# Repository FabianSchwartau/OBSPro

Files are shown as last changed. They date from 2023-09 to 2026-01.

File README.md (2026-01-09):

# OBSPro
This is a different version of the OpenBikeSensor main PCB (checkout https://github.com/openbikesensor/OpenBikeSensor_PCB_Board) with a few design goals:
* Optimized for pick-and-place manufacturing. This means no modules for each functionality, everything is on a single board and SMD parts are used.
* Parts only from trustworthy and reliable sources. This also includes that it should be possible to order these parts with a proper bill.
* Software compatibility as far as possible with the original hardware/software.

# PCBA
At the moment we are aiming to get almost all parts from LCSC/JLCPCB, which is a good mixture of trustworthiness/reliability and price. JLC also offers a PCB assemby service, which is used. If you only want one or two boards, it is probably not woth it, but for larger orders it makes perfect sense.

# GPS
There are multiple options for the GPS module. You can use any MAX-8* or MAX-10* from u-blox, which cost around 20€ for single quantities. The pinout is also compatible with the ATGM336H-5N* modules from Zhongkewei. It only costs around 5€, but the performance still needs to be evaluated.

# BOM
Here is a list of parts and potential sources you will need besides the parts listed in the BOM file of the PCB itself.

- THT PCB parts
    - These are also included in the PCB BOM, but not populated by us in the kit.
    - 1x display jack:
        - JST-  S5B-XH-A(LF)(SN): [LCSC](https://www.lcsc.com/product-detail/C263757.html)
    - 1x power switch jack:
        - JST - S2B-XH-A(LF)(SN): [LCSC](https://www.lcsc.com/product-detail/C157931.html)
    - 1x battery jack:
        - XKB Connection - X2510WR-02-N0SN: [LCSC](https://www.lcsc.com/product-detail/C843326.html)
    - 2x ultrasonic transducer
        - HYDZ: HY40A16T12-1: [LCSC](https://www.lcsc.com/product-detail/C17701106.html)
- GPS antenna
    - BAT WIRELESS - BWGNSCNX25-25B1Y2L120: [LCSC](https://www.lcsc.com/product-detail/C784385.html)
- Battery
    - Probably any 18650 style Lipo battery will do. As you need to solder the connectors to the battery, one with U-shaped strips already attached is recommended.
    - Samsung - INR18650-20R [akkuteile.de](https://www.akkuteile.de/lithium-ionen-akkus/18650/samsung/samsung-inr18650-20r-2000mah-3-7v-10c-20a-powertoolzelle-u-loetfahne_1006511_1668)
    - Multiple: [akkuservice-krueger.de](https://www.akkuservice-krueger.de/epages/64221289.sf/de_DE/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) (you can select with solder strip for each battery)
- Battery cable + connector + crimp contacts
    - 1x complete assembly: XKB Connection - X2510T-02-PSN-A22RB-L300-T5: [LCSC](https://www.lcsc.com/product-detail/C7423671.html) (if you buy this, you do not need the parts below)
    - 1x connector: XKB Connection - X2510H-02-N0: [LCSC](https://www.lcsc.com/product-detail/C843320.html)
    - 2x crimp contacts: XKB Connection - X2510T-PSN: [LCSC](https://www.lcsc.com/product-detail/C883292.html)
    - 2x cable (use any ~0.25mm² cable you can find, same for power switch connector)
- 2x zip ties
    - Maximum width: 4.5 mm, minimum length: 70 mm.
    - [LCSC](https://www.lcsc.com/product-detail/C5264191.html), [LCSC](https://www.lcsc.com/product-detail/C4944856.html), [LCSC](https://www.lcsc.com/product-detail/C5197740.html), your local hardware store, ...
- 1x Power switch
    - YUEN FUNG - MT-0-102-A101-M200-RS: [LCSC](https://www.lcsc.com/product-detail/C1788492.html)
- Power switch cable + connector + crimp contacts
    - 1x complete assembly: SHOU HAN - 2.54-2P DT 200mm 24AWG: [LCSC](https://www.lcsc.com/product-detail/C5363463.html) (if you buy this, you do not need the parts below)
    - 1x connector: JST - XHP-2: [LCSC](https://www.lcsc.com/product-detail/C144401.html)
    - 2x crimp contacts: JST - SXH-001T-P0.6: [LCSC](https://www.lcsc.com/product-detail/C140573.html?s_z=n_C140573) (same for the display connector!)
    - 2x cable (use any ~0.25mm² cable you can find, same for battery connector)
- 1x SD card
    - MK - MKUS128M-IGT1: [LCSC](https://www.lcsc.com/product-detail/C22374947.html)
    - SDTRUVAL - SDSDQAB-128M-SDWHA: [LCSC](https://www.lcsc.com/product-detail/C51885978.html)
- 8x Threaded insert nuts M3, ~5mm length, ~4.2mm outer diameter
    - Multiple: [Aliexpress](https://de.aliexpress.com/item/1005003453080262.html), [ruthex](https://www.ruthex.de/products/ruthex-gewindeeinsatz-m3-100-stuck-rx-m3x5-7-messing-gewindebuchsen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), [Amazon](https://www.amazon.de/Einpressmuttern-Einschmelzgewinde-Gewindeeins%C3%A4tze-Inschmelzmuttern-Kunststoffteile/dp/B0D3DZXT4R/), [Amazon](https://www.amazon.de/Gewindeeinsatz-Einschmelzgewinde-Einpressmuttern-Gewindebuchse-Kunststoffschale/dp/B0D17FGQWW/)
- 14x M3x8 screws (DIN912)
    - Used for: 4x main housing, 4x PCB, 3x display housing, 2x display cable strain relive, 4x main housing mounting.
    - Multiple: [Gedex](https://www.gedex-shop.de/de/schrauben/INNENSECHKANT/Zylinderkopf-DIN-912/DIN-912-M3-Innensechskantschrauben-mit-Zylinderkopf-Edelstahl-rostfrei-A2/DIN-912-M3-Innens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), [LCSC](https://www.lcsc.com/product-detail/C5138485.html), [LCSC](https://www.lcsc.com/product-detail/C7576553.html), [LCSC](https://www.lcsc.com/product-detail/C2931407.html)
- 1x M3x30 screw (DIN912)
    - Used for the locking pin.
    - Multiple: [Gedex](https://www.gedex-shop.de/de/schrauben/INNENSECHKANT/Zylinderkopf-DIN-912/DIN-912-M3-Innensechskantschrauben-mit-Zylinderkopf-Edelstahl-rostfrei-A2/DIN-912-M3-Innens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), [LCSC](https://www.lcsc.com/product-detail/C7576562.html)
- 6x M3 nuts (DIN934)
    - Used for: 4x main housing mount, 2x cable strain relief for display unit.
    - Multiple: [Gedex](https://www.gedex-shop.de/de/MUTTERN/Sechskantmuttern-FORM-B--NIEDRIG--MIT-FASE--DIN-5206/Sechskantmuttern-DIN-934/Sechskantmuttern-DIN-934-M3/), [LCSC](https://www.lcsc.com/product-detail/C357432.html)
- Display cable + connector + crimp contacts
    - 1x complete assembly: TBD (if you buy this, you do not need the parts below)
    - 1x connector: JST - XHP-5: [LCSC](https://www.lcsc.com/product-detail/C144404.html), [LCSC](https://www.lcsc.com/product-detail/C339274.html)
    - 2x crimp contacts: JST - SXH-001T-P0.6: [LCSC](https://www.lcsc.com/product-detail/C140573.html?s_z=n_C140573) (same for the power switch connector!)
    - 1x 2m cable: Lapp - Unitronic Sensor LIFY11Y 5x0.25 7038862: [automation24.de](https://www.automation24.de/pur-sensorleitung-lapp-unitronic-sensor-lify11y-5x0-25-bk-7038862)
- 1x OLED Display
    - Multiple: [Aliexpress](https://de.aliexpress.com/item/32896971385.html), [Alibaba](https://www.alibaba.com/product-detail/TZT-ROHS-Certification-0-96-inch_1600751684857.html), [LCSC](https://www.lcsc.com/product-detail/C5248080.html) (does not fit)
- 1x Display button
    - Daier - PBS-33B: [chinadaier.com](https://www.chinadaier.com/pbs-33b-mini-round-momentary-push-button-switch/) (for mass order)
    - Multiple: [Aliexpress](https://de.aliexpress.com/item/1005003302861259.html)
- 2x Display magnets
    - Multiple: [supermagenete.de](https://www.supermagnete.de/quadermagnete-neodym/quadermagnet-20mm-10mm-2mm_Q-20-10-02-N), [sprintis.de](https://www.sprintis.de/Magnete/Neodym-Magnete/Quadermagnete/Quadermagnete-aus-Neodym-selbstklebend-vernickelt-20-x-10-mm-2-mm.html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) (with glue), [sprintis.de](https://www.sprintis.de/Magnete/Neodym-Magnete/Quadermagnete/Quadermagnete-aus-Neodym-vernickelt-20-x-10-mm-2-mm.html) (without glue)
- 3D printed parts
    - It is recommended to print in PETG or ASA, PLA may also work but is brittle.
    - Main case (required): 1x [MainCaseBottom](https://github.com/FabianSchwartau/OBSPro/blob/main/mechanics/MainCaseBottom.stl), 1x [MainCaseTop](https://github.com/FabianSchwartau/OBSPro/blob/main/mechanics/MainCaseTop.stl), 1x [MainCaseSlideCover](https://github.com/FabianSchwartau/OBSPro/blob/main/mechanics/MainCaseSlideCover.stl)
    - Display case (required): 2x [DisplayCableStrainRelief](https://github.com/openbikesensor/OpenBikeSensor3dPrintableCase/blob/main/export/DisplayCase/DisplayCableStrainRelief.stl), 1x [DisplayCaseBottom](https://github.com/openbikesensor/OpenBikeSensor3dPrintableCase/blob/main/export/DisplayCase/DisplayCaseBottom.stl), 1x [DisplayCaseTop](https://github.com/openbikesensor/OpenBikeSensor3dPrintableCase/blob/main/export/DisplayCase/DisplayCaseTop.stl), 1x [HandlebarRail](https://github.com/openbikesensor/OpenBikeSensor3dPrintableCase/blob/main/export/Mounting/HandlebarRail.stl)
    - Mounting (required): 1x [StandardMountAdapter](https://github.com/openbikesensor/OpenBikeSensor3dPrintableCase/blob/main/export/Mounting/StandardMountAdapter.stl), 1x [LockingPin](https://github.com/openbikesensor/OpenBikeSensor3dPrintableCase/blob/main/export/Mounting/LockingPin.stl)
    - Mounting (user specific): 1x [SeatPostMount](https://github.com/openbikesensor/OpenBikeSensor3dPrintableCase/blob/main/export/Mounting/SeatPostMount.stl) or any other mount from [here](https://www.openbikesensor.org/docs/classic/case/parts/)

# Current preview
Here is an image of the current board. The parts are roughly placed and a small part is routed. Also there are a bunch of 3D models still missing.

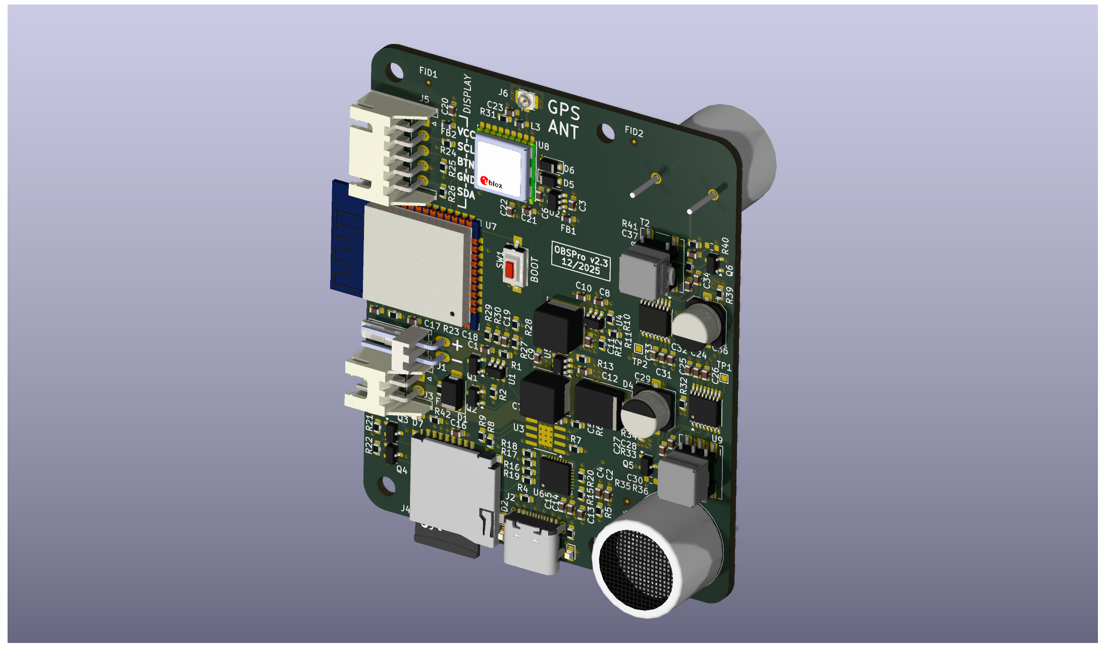
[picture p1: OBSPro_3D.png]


# Software
TODO: Link to the software and how to flash the device.

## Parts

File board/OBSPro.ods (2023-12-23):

Item | Qty | Reference(s) | Value | LibPart | JLC_PN | JLC_Price1 | JLC_Price10 | JLC_Price100 | JLC_Price1000
1 | 1 | AE1 | Antenna_Chip | Device:Antenna_Chip | C239243 | 1,0297 | 0,8651 | 0,5724 | 0,6065 | 1,0297 | 0,8651 | 0,5724 | 0,6065
2 | 1 | BT1 | LiPo | Device:Battery_Cell | C2979182 | 0,591 | 0,591 | 0,4208 | 0,3288 | 0,591 | 0,591 | 0,4208 | 0,3288
3 | 3 | C1, C4, C5 | 10u | Device:C_Small | C19702 | 0,062 | 0,0062 | 0,0031 | 0,0029 | 0,186 | 0,0186 | 0,0093 | 0,0087
4 | 8 | C2, C6, C8, C9, C10, C12, C15, C22 | 100n | Device:C_Small | C14663 | 0,042 | 0,0042 | 0,0021 | 0,0014 | 0,336 | 0,0336 | 0,0168 | 0,0112
5 | 1 | C3 | 220p | Device:C_Small | C1603 | 0,11 | 0,011 | 0,0055 | 0,0042 | 0,11 | 0,011 | 0,0055 | 0,0042
6 | 2 | C7, C11 | 1u | Device:C_Small | C15849 | 0,056 | 0,0056 | 0,0028 | 0,0027 | 0,112 | 0,0112 | 0,0056 | 0,0054
7 | 2 | C13, C14 | 18p | Device:C_Small |  |  |  |  |  | 0 | 0 | 0 | 0
8 | 8 | C16, C17, C20, C21, C23, C24, C27, C28 | 10n | Device:C_Small |  |  |  |  |  | 0 | 0 | 0 | 0
9 | 4 | C18, C19, C25, C26 | 1n | Device:C_Small |  |  |  |  |  | 0 | 0 | 0 | 0
10 | 1 | D1 | D_Schottky_Small | Device:D_Schottky_Small |  |  |  |  |  | 0 | 0 | 0 | 0
11 | 1 | D2 | CH_GR | Device:LED | C2297 | 0,274 | 0,0274 | 0,0137 | 0,0096 | 0,274 | 0,0274 | 0,0137 | 0,0096
12 | 1 | D3 | CH_RE | Device:LED | C2286 | 0,106 | 0,0106 | 0,0053 | 0,0036 | 0,106 | 0,0106 | 0,0053 | 0,0036
13 | 2 | D4, D5 | D_Small | Device:D_Small |  |  |  |  |  | 0 | 0 | 0 | 0
14 | 1 | J1 | USB | Connector:USB_C_Receptacle_USB2.0 | C165948 | 0,1675 | 0,1309 | 0,0972 | 0,0902 | 0,1675 | 0,1309 | 0,0972 | 0,0902
15 | 1 | J2 | SWIM | Connector_Generic:Conn_01x04 | C225256 | 0,1105 | 0,0442 | 0,0179 | 0,0142 | 0,1105 | 0,0442 | 0,0179 | 0,0142
16 | 2 | L1, L2 | 4.7u | Device:L_Small | C57269 | 0,2555 | 0,0511 | 0,0414 | 0,0284 | 0,511 | 0,1022 | 0,0828 | 0,0568
17 | 2 | LS1, LS3 | TX1 | Device:Speaker | C242190 | 1,6534 | 1,4371 | 1,1629 | 1,072 | 3,3068 | 2,8742 | 2,3258 | 2,144
18 | 2 | LS2, LS4 | RX1 | Device:Speaker | C242190 | 1,6534 | 1,4371 | 1,1629 | 1,072 | 3,3068 | 2,8742 | 2,3258 | 2,144
19 | 1 | Q1 | AP2302B | Device:Q_NMOS_DGS | C406812 | 0,176 | 0,0176 | 0,0137 | 0,0107 | 0,176 | 0,0176 | 0,0137 | 0,0107
20 | 2 | Q2, Q3 | AP2302B | Device:Q_NMOS_GSD | C406812 | 0,176 | 0,0176 | 0,0137 | 0,0107 | 0,352 | 0,0352 | 0,0274 | 0,0214
21 | 2 | Q4, Q5 | S8050 | Device:Q_NPN_BEC | C2146 | 0,216 | 0,0216 | 0,0144 | 0,0098 | 0,432 | 0,0432 | 0,0288 | 0,0196
22 | 1 | R1 | 82k | Device:R_Small |  |  |  |  |  | 0 | 0 | 0 | 0
23 | 2 | R2, R3 | 5.1k | Device:R_Small |  |  |  |  |  | 0 | 0 | 0 | 0
24 | 1 | R4 | 16.9k | Device:R_Small |  |  |  |  |  | 0 | 0 | 0 | 0
25 | 7 | R5, R7, R15, R16, R17, R21, R34 | 10k | Device:R_Small |  |  |  |  |  | 0 | 0 | 0 | 0
26 | 1 | R6 | 680 | Device:R_Small |  |  |  |  |  | 0 | 0 | 0 | 0
27 | 1 | R8 | 1.66k | Device:R_Small |  |  |  |  |  | 0 | 0 | 0 | 0
28 | 3 | R9, R24, R37 | 1k | Device:R_Small |  |  |  |  |  | 0 | 0 | 0 | 0
29 | 8 | R10, R18, R19, R20, R29, R32, R33, R42 | 4.7k | Device:R_Small |  |  |  |  |  | 0 | 0 | 0 | 0
30 | 4 | R11, R12, R13, R14 | 220 | Device:R_Small |  |  |  |  |  | 0 | 0 | 0 | 0
31 | 2 | R22, R35 | 56k | Device:R_Small |  |  |  |  |  | 0 | 0 | 0 | 0
32 | 2 | R23, R36 | 6.2k | Device:R_Small |  |  |  |  |  | 0 | 0 | 0 | 0
33 | 6 | R25, R27, R30, R38, R40, R43 | 75k | Device:R_Small |  |  |  |  |  | 0 | 0 | 0 | 0
34 | 2 | R26, R39 | 7.5k | Device:R_Small |  |  |  |  |  | 0 | 0 | 0 | 0
35 | 2 | R28, R41 | 120k | Device:R_Small |  |  |  |  |  | 0 | 0 | 0 | 0
36 | 2 | R31, R44 | 3.3M | Device:R_Small |  |  |  |  |  | 0 | 0 | 0 | 0
37 | 1 | U1 | ADP1613 | OBSPro:ADP1613 | C132279 | 0,9294 | 0,7852 | 0,6144 | 0,5752 | 0,9294 | 0,7852 | 0,6144 | 0,5752
38 | 1 | U2 | TP4054 | OBSPro:TP4054 | C668215 | 0,2825 | 0,113 | 0,0455 | 0,0358 | 0,2825 | 0,113 | 0,0455 | 0,0358
39 | 1 | U3 | DW01A-G | OBSPro:DW01x | DW01A-G | 0,6005 | 0,1201 | 0,0982 | 0,079 | 0,6005 | 0,1201 | 0,0982 | 0,079
40 | 1 | U4 | CP2102N | Interface_USB:CP2102N-Axx-xQFN28 | C6568 | 2,1016 | 1,8524 | 1,5155 | 1,4105 | 2,1016 | 1,8524 | 1,5155 | 1,4105
41 | 1 | U5 | ESP32-WROOM-32 | RF_Module:ESP32-WROOM-32 | C82899 | 2,448 | 2,448 | 2,3571 | 2,3571 | 2,448 | 2,448 | 2,3571 | 2,3571
42 | 1 | U6 | STM8S003F3P | MCU_ST_STM8:STM8S003F3P | C18615 | 0,7209 | 0,7084 | 0,7084 | 0,7084 | 0,7209 | 0,7084 | 0,7084 | 0,7084
43 | 1 | U7 | MAX-M8C | RF_GPS:MAX-M8C |  | 21 | 15,73 | 10,32 | 10,32 | 21 | 15,73 | 10,32 | 10,32
44 | 2 | U8, U9 | LM324 | Amplifier_Operational:LM324 | C71035 | 0,1235 | 0,0971 | 0,0728 | 0,0696 | 0,247 | 0,1942 | 0,1456 | 0,1392
45 | 1 | Y1 | 16MHz | Device:Crystal_GND24_Small | C280090 | 0,772 | 0,1544 | 0,1268 | 0,1002 | 0,772 | 0,1544 | 0,1268 | 0,1002
 |  |  |  |  |  |  |  |  |  | 40,2092 | 29,7959 | 21,9003 | 21,2043
 |  |  |  |  |  |  |  |  | Parts | 40,2092 | 297,959 | 2190,03 | 21204,3
 |  |  |  |  |  |  |  |  | PCB | 2 | 5 | 57 | 475
 |  |  |  |  |  |  |  |  | Setup | 25 | 25 | 25 | 25
 |  |  |  |  |  |  |  |  | Stencil | 9 | 9 | 9 | 9
 |  |  |  |  |  |  |  |  | Pads | 1 | 10 | 100 | 1000
 |  |  |  |  |  |  |  |  | Extended | 20,85 | 20,85 | 20,85 | 20,85 | 1.39/part, 15 parts
 |  |  |  |  |  |  |  |  | Total | 98,0592 | 367,809 | 2401,88 | 22734,15
 |  |  |  |  |  |  |  |  | Per OBS | 98,0592 | 36,7809 | 24,0188 | 22,73415
 |  |  |  |  |  |  |  |  | Self-Assembl | 76,2092 | 33,6959 | 22,8103 | 21,7133

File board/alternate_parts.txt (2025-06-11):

C111600 UWX1C101MCL1GB -> C340733 UUD1C101MCL1GS

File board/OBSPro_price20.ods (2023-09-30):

Qty | Reference(s) | Value | JLC_BasicPart | JLC_Price10 | 20x Material | Setup | 20x Assembly*
1 | AE1 | Antenna_Chip | no | $0,8696 | $17,3920 | $0,0000 | $0,0068
1 | BT1 | LiPo | no | $0,0079 | $0,1580 | $0,0000 | $0,0068
10 | C1; C2; C3; C4; C7; C8; C10; C11; C12; C13 | 22u | no | $0,0217 | $4,3400 | $0,0000 | $0,0680
5 | C5; C6; C15; C16; C21 | 10u | yes | $0,0052 | $0,5200 | $3,0000 | $0,0340
7 | C9; C14; C18; C19; C20; C25; C26 | 100n | yes | $0,0021 | $0,2940 | $3,0000 | $0,0476
1 | C17 | 1u | yes | $0,0051 | $0,1020 | $3,0000 | $0,0068
11 | C22; C23; C24; C28; C29; C32; C40; C45; C46; C49; C57 | 100n | yes | $0,0021 | $0,4620 | $3,0000 | $0,0748
10 | C27; C30; C31; C35; C36; C44; C47; C48; C52; C53 | 10u | yes | $0,0237 | $4,7400 | $3,0000 | $0,0680
4 | C33; C34; C50; C51 | 18p | yes | $0,0064 | $0,5120 | $3,0000 | $0,0272
6 | C37; C38; C39; C54; C55; C56 | 820p | no | $0,0038 | $0,4560 | $0,0000 | $0,0408
4 | C41; C43; C58; C60 | 10p | yes | $0,0054 | $0,4320 | $3,0000 | $0,0272
2 | C42; C59 | 1u | yes | $0,0051 | $0,2040 | $3,0000 | $0,0136
5 | D1; D2; D3; D6; D7 | LED | yes | $0,0248 | $2,4800 | $3,0000 | $0,0340
2 | D4; D5 | D_Small | yes | $0,0064 | $0,2560 | $3,0000 | $0,0136
1 | J1 | USB | no | $0,2007 | $4,0140 | $0,0000 | $0,0068
1 | J2 | BTN_DISP | no | $0,0194 | $0,3880 | $0,0000 | $0,0068
1 | J3 | MicroSD | no | $0,1622 | $3,2440 | $0,0000 | $0,0068
1 | J4 | PROG | no | $0,0325 | $0,6500 | $0,0000 | $0,0068
1 | L1 | 1u | no | $0,0815 | $1,6300 | $0,0000 | $0,0068
1 | L2 | 3,3u | no | $0,0766 | $1,5320 | $0,0000 | $0,0068
4 | LS1; LS2; LS3; LS4 | Speaker | no | $1,2985 | $103,8800 | $0,0000 | $0,0272
2 | Q1; Q2 | S8050 | yes | $0,0137 | $0,5480 | $3,0000 | $0,0136
4 | Q3; Q4; Q5; Q6 | 2N7002 | yes | $0,0014 | $0,1120 | $3,0000 | $0,0272
12 | R1; R6; R8; R24; R28; R29; R34; R35; R38; R39; R44; R52 | 1k | yes | $0,0005 | $0,1200 | $3,0000 | $0,0816
2 | R2; R3 | 5,1k | yes | $0,0009 | $0,0360 | $3,0000 | $0,0136
1 | R4 | 2 | yes | $0,0012 | $0,0240 | $3,0000 | $0,0068
1 | R5 | 0,5 | no | $0,0025 | $0,0500 | $0,0000 | $0,0068
1 | R7 | 33,2k | no | $0,0009 | $0,0180 | $0,0000 | $0,0068
8 | R9; R11; R17; R18; R19; R22; R25; R27 | 10k | yes | $0,0013 | $0,2080 | $3,0000 | $0,0544
3 | R12; R46; R54 | 4,7k | yes | $0,0010 | $0,0600 | $3,0000 | $0,0204
4 | R13; R14; R15; R16 | 220 | yes | $0,0009 | $0,0720 | $3,0000 | $0,0272
2 | R20; R21 | 1,1k | no | $0,0009 | $0,0360 | $0,0000 | $0,0136
2 | R23; R26 | 1M | yes | $0,0009 | $0,0360 | $3,0000 | $0,0136
10 | R30; R32; R40; R41; R42; R43; R48; R49; R50; R51 | 6,8k | yes | $0,0009 | $0,1800 | $3,0000 | $0,0680
2 | R31; R33 | 68k | yes | $0,0009 | $0,0360 | $3,0000 | $0,0136
6 | R36; R37; R45; R47; R53; R55 | 220k | yes | $0,0009 | $0,1080 | $3,0000 | $0,0408
1 | RV1 | 1k | no | $0,1247 | $2,4940 | $0,0000 | $0,0068
1 | U1 | IP5306 | no | $0,1766 | $3,5320 | $0,0000 | $0,0068
1 | U2 | TPS562201 | no | $0,1185 | $2,3700 | $0,0000 | $0,0068
1 | U3 | RT9069 | no | $0,3239 | $6,4780 | $0,0000 | $0,0068
1 | U4 | CP2102N | yes | $1,9728 | $39,4560 | $3,0000 | $0,0068
1 | U5 | ESP32-WROOM-32 | no | $2,5318 | $50,6360 | $0,0000 | $0,0068
1 | U6 | LM393 | yes | $0,3586 | $7,1720 | $3,0000 | $0,0068
1 | U7 | MAX-M8C | no | $15,0700 | $301,4000 | $0,0000 | $0,0068
2 | U8; U11 | NE5532 | yes | $0,2156 | $8,6240 | $3,0000 | $0,0136
2 | U9; U12 | STM8S003F3P | yes | $0,3668 | $14,6720 | $3,0000 | $0,0136
2 | U10; U13 | MAX202 | no | $1,1165 | $44,6600 | $0,0000 | $0,0136
2 | Y1; Y2 | 8MHz | yes | $0,1689 | $6,7560 | $3,0000 | $0,0136
 |  |  |  | Sum: | $637,58 | $81,00 | $21,08
 |  |  |  | Setup: | $8,00
 |  |  |  | Stencil: | $1,50
 |  |  |  | Shipping: | $50,00
 |  |  |  | Total: | $749,16
 |  |  |  | Total per OBS: | $37,46
 | * 0,0017$ pro SMD-Pin, geschätzt mit 4 Pins pro Komponente

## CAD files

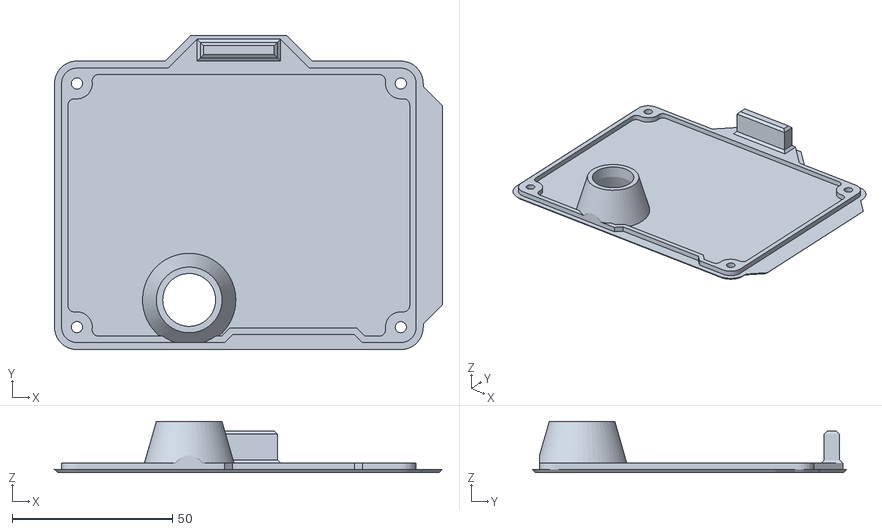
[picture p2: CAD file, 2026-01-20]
mechanics/MainCaseTop.stl
121.0 x 98.0 x 16.0

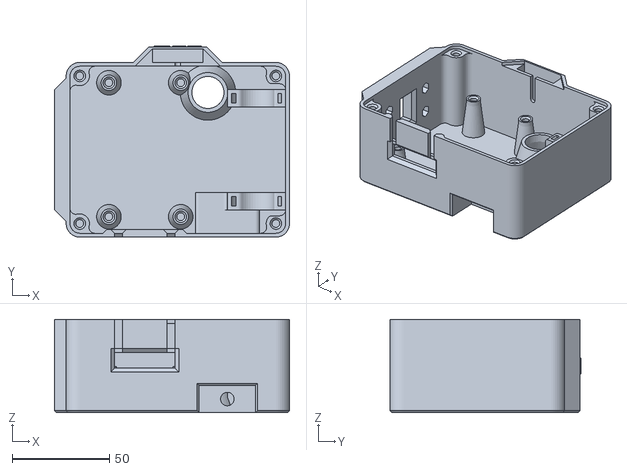
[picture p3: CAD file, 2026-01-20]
mechanics/MainCaseBottom.stl
121.0 x 98.5 x 48.0

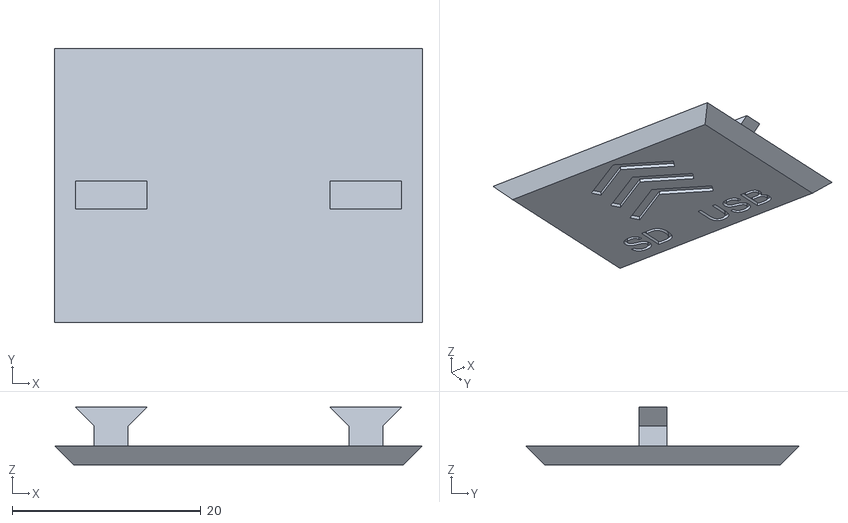
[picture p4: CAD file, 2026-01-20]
mechanics/MainCaseSlideCover.stl
39.0 x 29.0 x 6.10

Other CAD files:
mechanics/MainCaseBottom.f3d
mechanics/MainCaseSlideCover.f3d
mechanics/MainCaseTop.f3d

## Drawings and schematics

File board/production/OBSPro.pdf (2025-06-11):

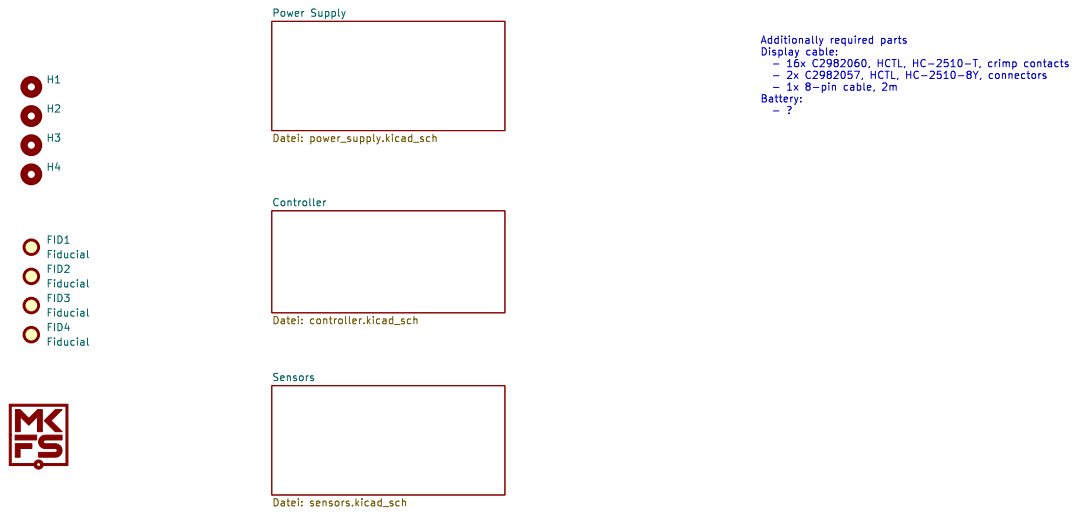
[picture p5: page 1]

Id: 1/6 Title: File: OBSPro.kicad_sch Sheet: /

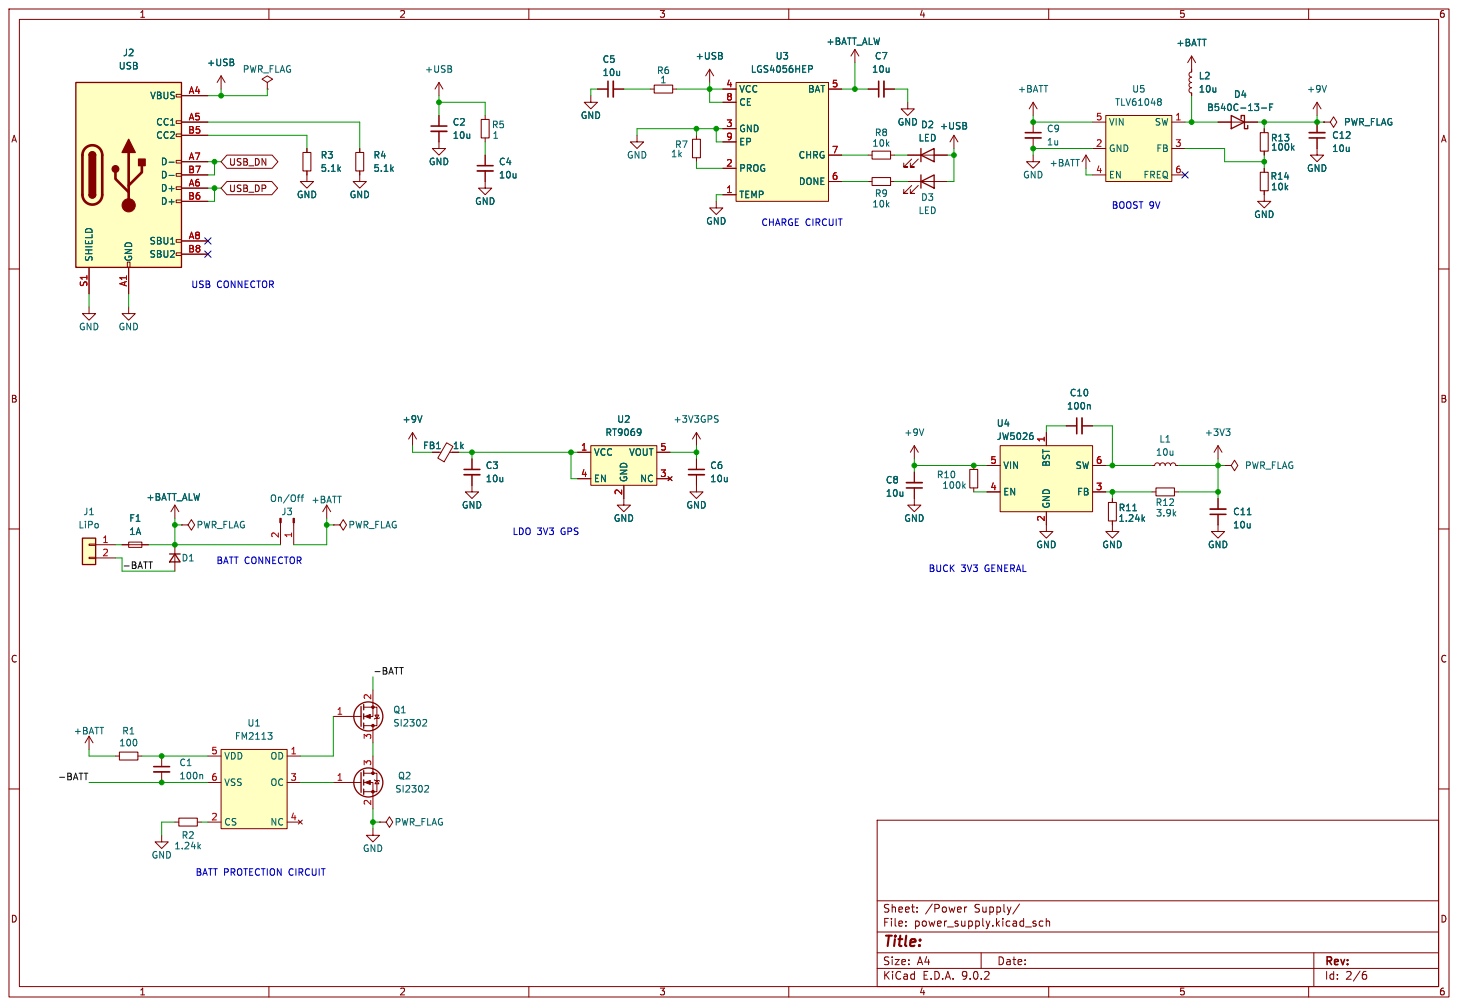
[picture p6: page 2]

BUCK 3V3 GENERAL BATT PROTECTION CIRCUIT BATT CONNECTOR

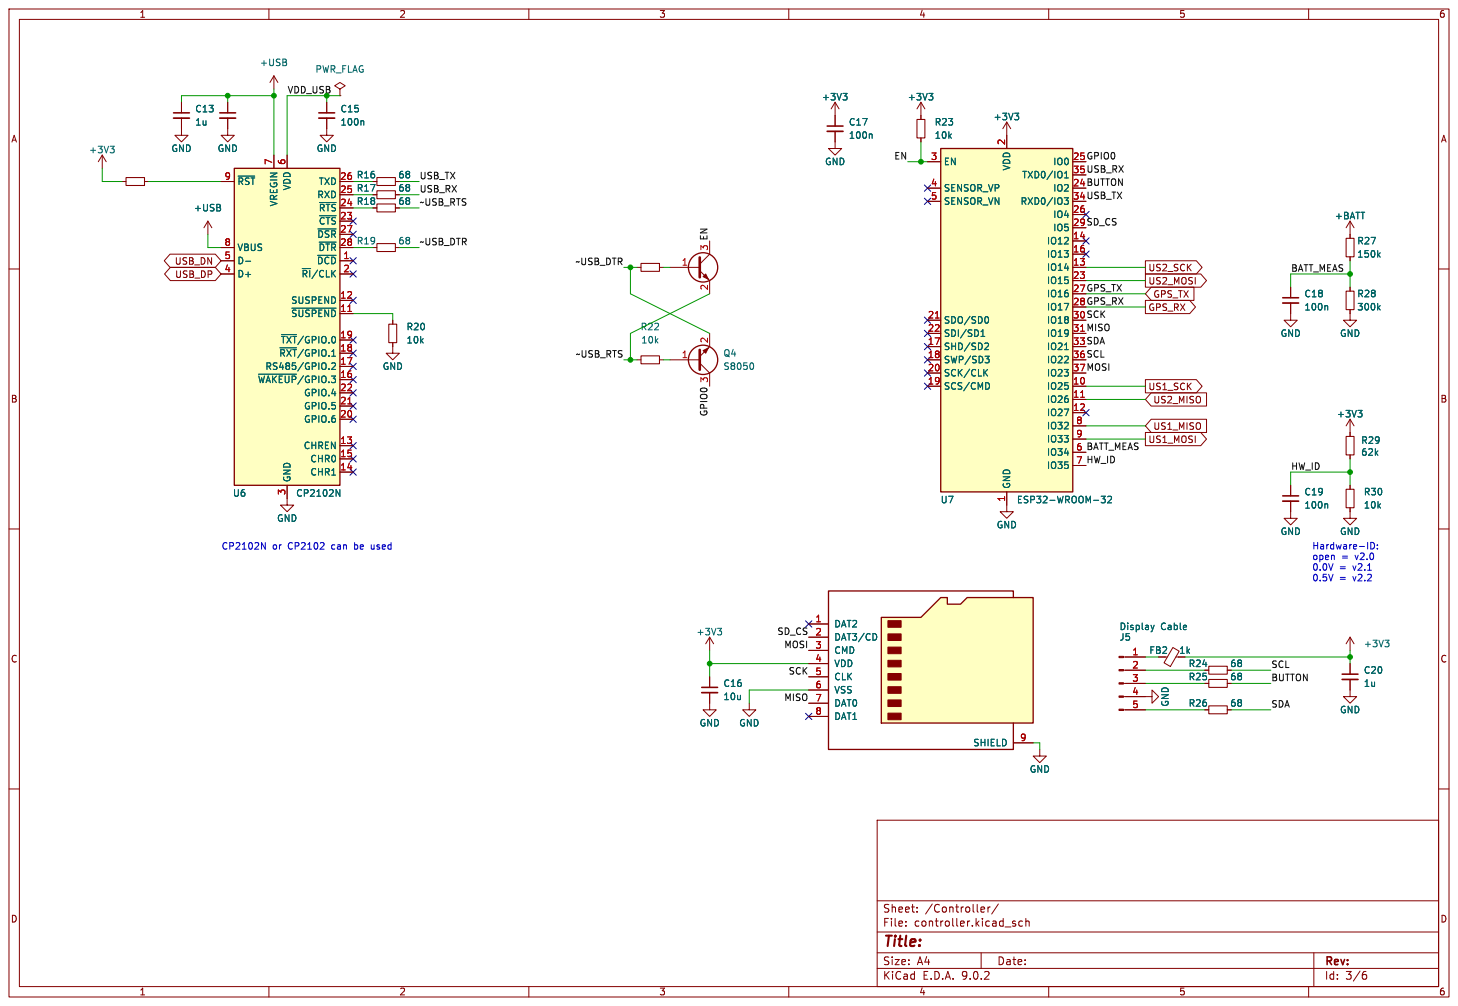
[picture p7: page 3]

3 TXD 26 RXD 25 ~{RTS} 24 ~{CTS} 23 ~{DSR} 27 ~{DTR} 28 ~{DCD}1 ~{RI}/CLK2 SUSPEND 12 ~{SUSPEND}11 ~{TXT}/GPIO.019 ~{RXT}/GPIO.118 RS485/GPIO.2 17 ~{WAKEUP}/GPIO.316 GPIO.4 22 GPIO.5 21 GPIO.6 20 CHREN 13 CHR0 15 CHR1 14 U6 CP2102N GND

3 TXD 26 RXD 25 ~{RTS} 24 ~{CTS} 23 ~{DSR} 27 ~{DTR} 28 ~{DCD}1 ~{RI}/CLK2 SUSPEND 12 ~{SUSPEND}11 ~{TXT}/GPIO.019 ~{RXT}/GPIO.118 RS485/GPIO.2 17 ~{WAKEUP}/GPIO.316 GPIO.4 22 GPIO.5 21 GPIO.6 20 CHREN 13 CHR0 15 CHR1 14 R20

Id: 3/6 Title: File: controller.kicad_sch Sheet: /Controller/

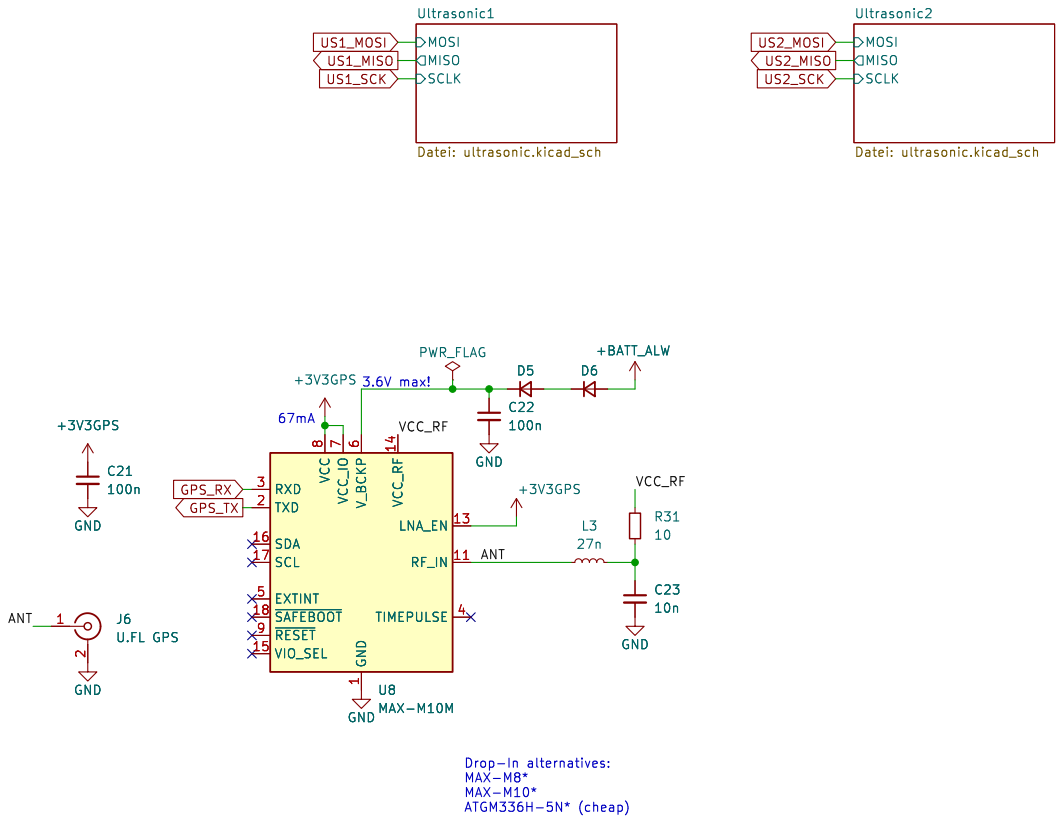
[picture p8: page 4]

1 VCC_RF 14 LNA_EN 13 RF_IN 11 TIMEPULSE 4 U8 MAX-M10M GND GND GND

Id: 4/6 Title: File: sensors.kicad_sch Sheet: /Sensors/

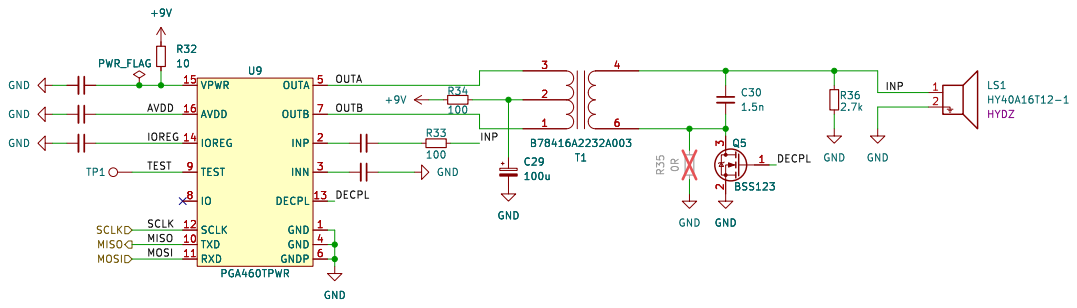
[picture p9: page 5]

Id: 5/6 Title: File: ultrasonic.kicad_sch Sheet: /Sensors/Ultrasonic1/

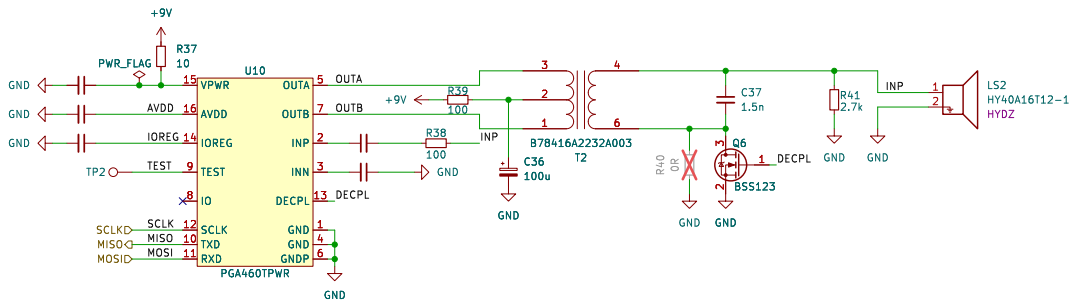
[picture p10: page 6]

Id: 6/6 Title: File: ultrasonic.kicad_sch Sheet: /Sensors/Ultrasonic2/

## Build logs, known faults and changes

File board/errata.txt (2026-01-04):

=== v1.0 ===
!* 5.1 Ohm in der Bestellung?
!* Die ganzen Handsolder Footprints durch normale ersetzen
!* BOM neu exportieren für richtiges Poti
!* BAT +/- beschriften
!* Anderen I/Os beschriften
!* SDA/SCL Pull-Ups durch 1k ersetzen
!* R27 am Button-Mosfet-Grab durch 1k ersetzen
!* 5V/3.3V Power-LEDs zu hell
!* 5V-LED könnte man einsparen und durch die am IP5306 ersetzen
!* RX/TX doppelt getauscht
!* LED2/3 am IP5306 müssen nach +BAT gehen
* I2C des IP5306 als Bestückungsoption?
!* Batterie-Spannungsteiler an Pin IO34 fehlt
* (Poly)fuse vor Batterie?
!* BTN_PRESS nicht angeschlossen (IO13)
!* Ultraschall macht beim boot irgendwas manchmal

Änderungen an der US-Schaltung:
* Mute-Widerstand auf 100R verringert
* Koppel-Cs im Rx Signalpfad von 820p auf 1.5n erhöht
* Serien-Rs im Rx Signalpfad von 6.8k auf 3.3k verringert
    -> Mit den Cs und Rs wird der Gain von ~27 dB auf ~33 dB angehoben, pro Stufe
* Widerstände für Vref: 330R (high), 680R (low)

=== v2.0 ===
!* Sicherung
!* Beads an Leitungen zum Display?
* ROHS prüfen
!* Die 9V haben ~3.3V durch die Diode des Step-Ups. Das führt zu ~22mA Standby Stromverbrauch
  Messen, was die 9V tatsächlich brauchen und wenn das gering genug ist, den Stepup über die 5V laufen lassen
!* Die 5V sind, auch wenn der IP5303 aus ist, mit 0,7-1,6V da - bei höheren Werten funktioniert die Button-Schaltung nicht mehr
  Ein Pull-Down an den 5V scheint ordentlich zu helfen. Bei ursprünglich 1,6V gehts mit 1k auf 0,4V runter. Mit 220R auf 0,1V.
  Interessanter weise sinkt dadurch der gesamte Stromverbrauch...
!* Power-Planes vom Rand weg ziehen
!* Die +BATT power Plane schneidet sich unten mit dem Sichtfenster und ist daher nur über nen hauch Tüdeldraht angeschlossen
!* USB Buchse (und SD-Karte?) weiter raus schauen lassen
!* Die Beads der Signale am Display-Stecker durch 220R ersetzen
* ESD-Dioden für die Signale zum Display?
!* IP5303 schaltet bei zu kleiner Last nach ~15 Sekunden aus
!* GPIOs 34-39 sind nur inputs!
  - SENSOR2_IO verlegt auf GPIO22
!* Synchronous UART für die PGA einzeln verbinden - MISO kann geteilt werden - das TCI Protokoll ist Müll
!* Time decoupling benutzen? Dann: DEPL Transistor Drain muss an pin 6 vom Trafo und Pins 6 vom Trafo darf nicht nach GND

=== v2.2 ===
!* Akku Polarität tauschen
!* Schutz-IC Versorgung an BATT_ALW statt +BATT
!* Flash Problematik prüfen -> Treiberproblem
!* Batteriebuchse falsche Ausführung? -> Nein, ist richtig
!* Boot-Button hinzufügen
!* Kupferzonen für vollkommene Ausfüllung über Kanten hinausziehen
!* Power-LED hinzufügen
!* OBS Logo auf Back Silkscreen

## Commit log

2022-10-19 New power management IC, some cleanup
    [OBSPro.kicad_sch, controller.kicad_sch, power_supply.kicad_sch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]
2022-11-24 Add kibot/kicost config and sample cost entry for antenna chip
    [OBSPro-kicost.xlsx, sensors.kicad_sch]
2022-11-24 Add kibot:JLC:pricing from existing columns
    [OBSPro-kicost.xlsx, controller.kicad_sch, power_supply.kicad_sch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]
2022-11-24 Add more footprints, prices and part numbers
    [OBSPro-kicost.xlsx, OBSPro.kicad_sch, controller.kicad_sch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]
2023-02-26 Added new ultrasonic circuit, changed the 3.3V regulator to a buck converter, and fixed some issues
    [OBSPro.kicad_sch, controller.kicad_sch, power_supply.kicad_sch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]
2023-02-26 First placement of parts, fixed a few bugs in the schematic
    [OBSPro.kicad_pcb, OBSPro.kicad_sch, controller.kicad_sch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]
2023-02-27 Swapped footprints of connectors, optimized placement
    [OBSPro.kicad_pcb, OBSPro.kicad_sch, controller.kicad_sch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]
2023-03-02 Replaced the component groups to get a tighter fit and routed most of the ultrasonic sensors
    [OBSPro.kicad_pcb, OBSPro.kicad_sch, sensors.kicad_sch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]
2023-03-04 Everything routed, a few changes in the components, first prototypes ordered
    [OBSPro.kicad_pcb, OBSPro.kicad_sch, controller.kicad_sch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]
2023-03-05 Fixed ERC/DRC errors, last cleanup before production data export
    [OBSPro.kicad_pcb, OBSPro.kicad_sch, controller.kicad_sch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]
2023-03-05 Gerber export
    [OBSPro.kicad_pcb]
2023-09-30 Updated price information for 10x and added a calculation for 20 boards including all parts and assembly cost
    [OBSPro.kicad_sch, OBSPro_price20.ods, controller.kicad_sch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]
2023-12-23 Created fabrication data for first prototypes
    [OBSPro-B_Cu.gbl, OBSPro-B_Mask.gbs, OBSPro-B_Paste.gbp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]
2023-12-23 First Version of the housing - very simple
    [MainCaseBottom.f3d, MainCaseBottom.ipt, MainCaseBottom.step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]
2023-12-23 Added custom test board for GPS antenna testing
    [OBSPro-B_Cu.gbl, OBSPro-B_Mask.gbs, OBSPro-B_Paste.gbp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]
2023-12-25 Updated schematic to new revision: Switch ultrasonic modules to PGA460, using ublox M10 GPS
    [controller.kicad_sch, power_supply.kicad_sch, sensors.kicad_sch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]
2023-12-25 Fixed ERC errors
    [controller.kicad_sch, power_supply.kicad_sch, sensors.kicad_sch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]
2023-12-25 Changed US-Transducer
    [ultrasonic.kicad_sch]
2023-12-25 Updated an cleaned board with new schematic
    [OBSPro.kicad_pcb, ultrasonic.kicad_sch]
2023-12-27 Changed battery connector to JST PH 2.0mm
    [OBSPro.kicad_pcb, controller.kicad_sch, power_supply.kicad_sch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]
2023-12-28 Changed display connector and switched to new SPI LCD
    [OBSPro.kicad_pcb, controller.kicad_sch]
2023-12-29 Rough placement of US electronics
    [OBSPro.kicad_pcb, controller.kicad_sch, power_supply.kicad_sch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]
2024-01-02 3D-Modelle hinzugefügt
    [OBSPro.kicad_pcb, OBSPro.kicad_sch, power_supply.kicad_sch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]
2024-01-03 Routing basically finished
    [OBSPro.kicad_pcb, controller.kicad_sch, power_supply.kicad_sch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]
2024-01-04 Added beads, fixed a few part numbers, exported gerber/drill This is the ordered version
    [OBSPro-B_Cu.gbl, OBSPro-B_Mask.gbs, OBSPro-B_Paste.gbp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]
2024-02-23 Fixed full errata, now v2.1 Most important changes: * Changed power supply architecture * Added hardware ID resistors * Moved USB connector closer to/over the border * Added a 2A fuse * Replaced Bead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
    [OBSPro-CuBottom.gbr, OBSPro-CuIn1.gbr, OBSPro-CuIn2.gbr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]
2024-02-25 Modified board to have copper pads on all layers for the vias (JLC is strange...)
    [OBSPro-CuBottom.gbr, OBSPro-CuIn1.gbr, OBSPro-CuIn2.gbr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]
2024-02-25 Added new housing, updated mechanics
    [DisplayCaseBottom.f3d, DisplayCaseTop.f3d, MainCaseBottom.f3d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]
2024-02-25 Removed GPS test board
    [OBSPro-B_Cu.gbl, OBSPro-B_Mask.gbs, OBSPro-B_Paste.gbp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]
2025-04-22 Hardware Revision
    [OBSPro.kicad_sch, controller.kicad_sch, power_supply.kicad_sch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]
2025-04-27 Fix errors in schematic for new board design
    [OBSPro.kicad_sch, controller.kicad_sch, power_supply.kicad_sch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]
2025-04-30 Schematic updates
    [controller.kicad_sch, power_supply.kicad_sch, ultrasonic.kicad_sch]
2025-04-30 Fix pcb layout error
    [OBSPro.kicad_pcb]
2025-05-28 Update PCB layout
    [OBSPro.kicad_pcb, power_supply.kicad_sch]
2025-06-08 Update schematic and PCB layout
    [OBSPro.kicad_pcb, controller.kicad_sch, power_supply.kicad_sch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]
2025-06-11 Updated production files and ordered PCBs
    [OBSPro-B_Cu.gbl, OBSPro-B_Mask.gbs, OBSPro-B_Paste.gbp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]
2025-06-14 Fix D1 footprint
    [power_supply.kicad_sch]
2025-06-14 Adjust layout to D1 footprint
    [OBSPro.kicad_pcb]
2025-10-31 Fix several hardware bugs, improve silkscreen text
    [OBSPro.kicad_pcb, controller.kicad_sch, power_supply.kicad_sch]
2025-12-04 Various PCB tweaks, add power LED, add BOOT button
    [OBSPro.kicad_pcb, controller.kicad_sch, power_supply.kicad_sch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]
2025-12-04 Update all case mechanics files
    [DisplayCaseBottom.f3d, DisplayCaseTop.f3d, MainCaseBottom.f3d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]
2025-12-04 Updated readme with BOM list
2025-12-04 Added cables, connectors, ... and cable assemblies
2025-12-04 Fixed a few minor BOM parts
2025-12-04 Updated 3D PCB preview
2025-12-10 Fixed a few BOM parts
2026-01-04 Add OBS Logo, fix charge IC 3D model, update errata
    [OBSPro.kicad_pcb, OBSPro.kicad_sch, power_supply.kicad_sch]
2026-01-07 Minor PCB improvements
    [OBSPro.kicad_pcb]
2026-01-09 Update BOM items in readme
2026-01-09 Add german supplier for insert nuts in readme
2026-01-20 Push updated case design
    [MainCaseBottom.f3d, MainCaseBottom.stl, MainCaseSlideCover.f3d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]
